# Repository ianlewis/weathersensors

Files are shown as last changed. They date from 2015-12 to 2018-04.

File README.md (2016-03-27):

# Home Sensors Project

This is my home sensors project.

## Architecture

The system will contain:

1. 2 temperature/humidity sensor modules for inside. One for upstairs and one for downstairs.
1. 1 temperature/humidity/barameter sensor module for outside (maybe also wind & rainfall).

Software will need to be written for each of the types of modules. Each of the
sensor modules will contain a web server which will return the current data
when queried. The aggregator module will polls data for each of the sensors and
streams that data to BigQuery.

Architecture

## Design

### Indoor sensor modules

The [indoor module](indoor_mod/) will read indoor temperature and humidity.

### Outdoor sensor modules

The [outdoor module](outdoor_mod/) will read outdoor temperature, humidity, atmospheric pressure, wind strength, wind direction, and rainfall.

### Aggregation App

The [aggregation server](aggre_mod/) will aggregate data and store it in BigQuery.

# Notes

## Local Development

Flashing devices locally requires the
[particle-cli](https://github.com/spark/particle-cli) and
[dfu-util](http://dfu-util.sourceforge.net/).

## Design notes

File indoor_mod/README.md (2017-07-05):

# Indoor sensor modules

The indoor sensor modules will be powered by the [Particle
Photon](https://particle.io/) module. Photons are USB powered and have an
integrated ARM microcontroller and wifi module. The device will use the
Particle Pub/Sub API to send new data to the aggregator module.

The indoor sensor modules will use the [AM2302 temperature & humidity
sensor](https://www.adafruit.com/products/393) and use a enclosure.

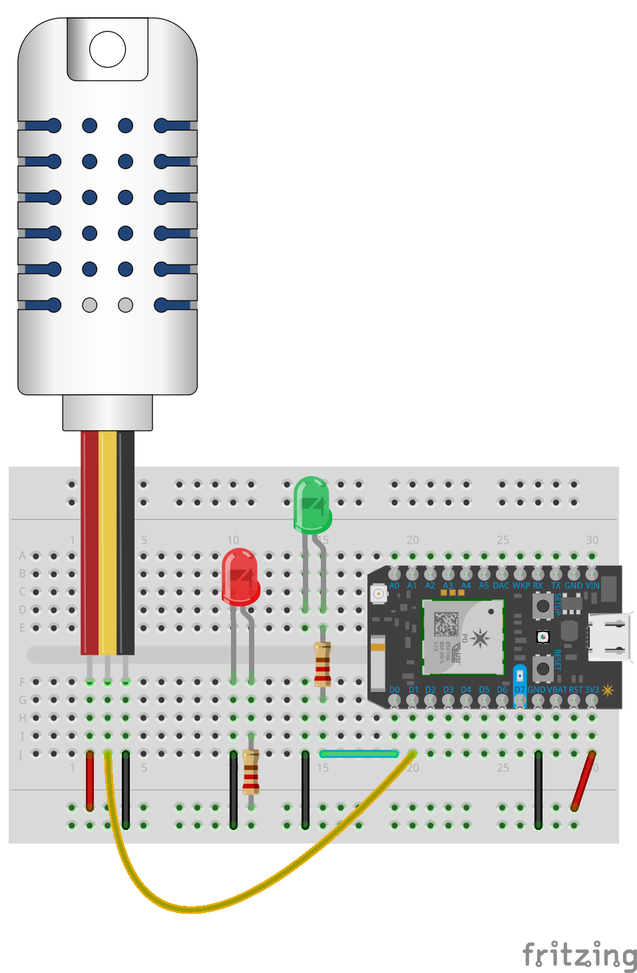
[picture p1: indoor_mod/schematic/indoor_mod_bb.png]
Schematic


## Build the Firmware

Building the firmware by running make in the firmware directory. You can learn more about building the photon firmware by reading the firmware [Getting Started](https://github.com/spark/firmware/blob/develop/docs/gettingstarted.md) page.

```
$ cd firmware
$ make
```

If you run into errors building the firmware sometimes they will resolve themselves by building from a clean version.

```
$ make clean firmware
```

## Flash the Firmware Locally

Flashing requires the `dfu-util` tool.

```
$ make program-dfu
```

## Flash the Firmware Remotely

Flashing the firmware remotely requires the [particle-cli](https://docs.particle.io/guide/tools-and-features/cli/photon/) tool.

TODO: Add instructions.

## Datasheets

Find info about the components used in the [datasheets](datasheets/) directory.

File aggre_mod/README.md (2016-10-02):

# Aggregator Module

This module is a data aggregator. It receives data published from devices and
forwards it on to Fluentd/BigQuery.

# Architecture

Architecture

# Setup

aggre\_mod is deployed to [Google Container
Engine](https://cloud.google.com/container-engine/) where it runs in a
[pod](http://kubernetes.io/v1.0/docs/user-guide/pods.html) with Fluentd.

The app is deployed via the following steps. You will need to have
make, Docker, and the Google Cloud SDK installed:

1. Create a BigQuery dataset.

        bq mk --description "Sensors Dataset" weathersensors

1. Create a BigQuery table.

        bq mk --description "Sensor data" weathersensors.sensordata schema.json

1. Create and push the container images (make sure you have the Google Cloud SDK installed and configured for your project):

        make clean image push

1. [Create a service account](https://cloud.google.com/iam/docs/creating-managing-service-accounts) and get the JSON key. Save it to the file 'service-account.json'.
1. Create the configmap:

        kubectl create configmap aggremod-conf \
            --from-literal=project-id=$(gcloud config list project | awk 'FNR==2 { print $3 }') \
            --from-literal=bigquery-dataset=weathersensors \
            --from-literal=bigquery-table=sensordata

1. Create the secret:

        kubectl create secret generic aggremod-secret \
            --from-literal=token=[particle.io token] \
            --from-file=service-account.json

1. Create the aggre\_mod Deployment:

        kubectl create -f deploy.yaml

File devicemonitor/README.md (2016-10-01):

# Device Monitor

This directory contains a device monitor that monitors [Particle](https://particle.io/) devices and creates error reports in [Stackdriver Error Reporting](https://cloud.google.com/error-reporting/) if they are offline for too long. The device monitor monitors the online status of each device or a subset of devices by polling the [Particle Devices API](https://docs.particle.io/reference/api/#devices).

## Usage

### Command line arguments

```shell
$ ./devicemonitor -help
Usage of ./devicemonitor:
  -access-token string
    	The path to a file containing the Particle API access token.
  -device-list string
    	The path to a text file of device IDs (one per line) to monitor. If not specified, all devices are monitored.
  -device-timeout int
    	The time that a device can be offline before an error is produced. (default 300)
  -host string
    	The web server address for health checks. (default ":8080")
  -poll-interval int
    	API polling interval in seconds. (default 30)
  -project string
    	The Google Cloud Platform project ID for the Error Reporting API.
  -version
    	Print the version and exit.
```

### Environment Variables

Some environment variables can be set to configure the monitor.

- **ADDRESS**: The address of the health check web server to bind to. This is overridden by the `-host` command line argument.
- **DEVICE_LIST_PATH**: The path to a text file of device IDs (one per line) to monitor. If not specified, all devices are monitored. This is overridden by the `-device-list` command line argument.
- **DEVICE_TIMEOUT**: The time in seconds that a device can be offline before an error is produced. This is overridden by the `-device-timeout` command line argument.
- **ACCESS_TOKEN_PATH**: The path to a file containing the Particle API access token. This is overridden by the `-access-token` command line argument.
- **POLL_INTERVAL**: API polling interval in seconds. This is overridden by the `-poll-interval` command line argument.
- **GCP_PROJECT**: The Google Cloud Platform project ID for the Error Reporting API. This is overridden by the `-project` command line argument.
- **GOOGLE_APPLICATION_CREDENTIALS**: The path to the service account JSON file. **Required.**

## Setup

This section will take you through how to set up the required files for the device monitor.

### Create the Service Account

Make sure you have the [Google Cloud Platform SDK](https://cloud.google.com/sdk/) installed and authenticated.

[Create a service account](https://cloud.google.com/iam/docs/creating-managing-service-accounts) for the device monitor.

```shell
$ gcloud iam service-accounts create devicemonitor --display-name "devicemonitor"
```

Create a service account key. This will output a `service-account.json` file.

```shell
$ gcloud iam service-accounts keys create service-account.json --iam-account devicemonitor@my-project.iam.gserviceaccount.com
```

### Create the Token file

Copy your [Particle access token](https://docs.particle.io/reference/api/#authentication) to the `token` file.

```shell
$ echo 9876987698769876987698769876987698769876 > token
```

### Create a Device List (Optional)

Create a list of device you want to monitor. This is optional. If you don't add a device list then all devices returned by the API will be monitored. The path to this file can be passed to the `DEVICE_LIST_PATH` environment variable or to the `-device-list` command line argument.

```shell
$ echo 0123456789abc > devices
$ echo 53ff6f0650723 >> devices
$ echo 53ff291839887 >> devices
```

### Build and Run the App

Building the app will require a relatively recent Go toolchain.

```shell
$ go generate
$ go build .
```

Alternatively, you can use make.

```shell
$ make clean devicemonitor
```

You can run the app from anywhere given yout pass in the right command line arguments.

```shell
$ GOOGLE_APPLICATION_CREDENTIALS=service-account.json ./devicemonitor -project-id=my-project -access-token=token
```

## Deploy on Kubernetes

There are Kubernetes deployment files included in the repository.

### Create the Secrets

Create the necessary secret.

```shell
$ kubectl create secret generic devicemonitor-secret --from-file=service-account.json --from-file=token
secret "devicemonitor-secret" created
```

### Create the ConfigMap

Create the ConfigMap by giving it a path to the `devices` file and passing it your Google Cloud Platform project ID.

```shell
$ kubectl create configmap devicemonitor-conf --from-file=devices --from-literal=project-id=my-project
configmap "devicemonitor-conf" created
```

### Deploy the Device Monitor

Create the deployment in Kubernetes.

```shell
$ kubectl create -f deploy.yaml
deployment "devicemonitor" created.
```

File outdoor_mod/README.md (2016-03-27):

# Outdoor sensor modules

The indoor sensor modules will also be powered by the [Particle
Photon](https://store.particle.io/?product=particle-photon) module. Photons are
USB powered and have an integrated ARM microcontroller and wifi module. The
device will use the Particle Pub/Sub API to send new data to the aggregator
module.

The outdoor sensor modules will use the [AM2315 - Encased I2C
Temperature/Humidity Sensor](https://www.adafruit.com/products/1293). The
outdoor module will also contain the [BMP180 Barometric
Pressure/Temperature/Altitude Sensor](https://www.adafruit.com/products/1603)

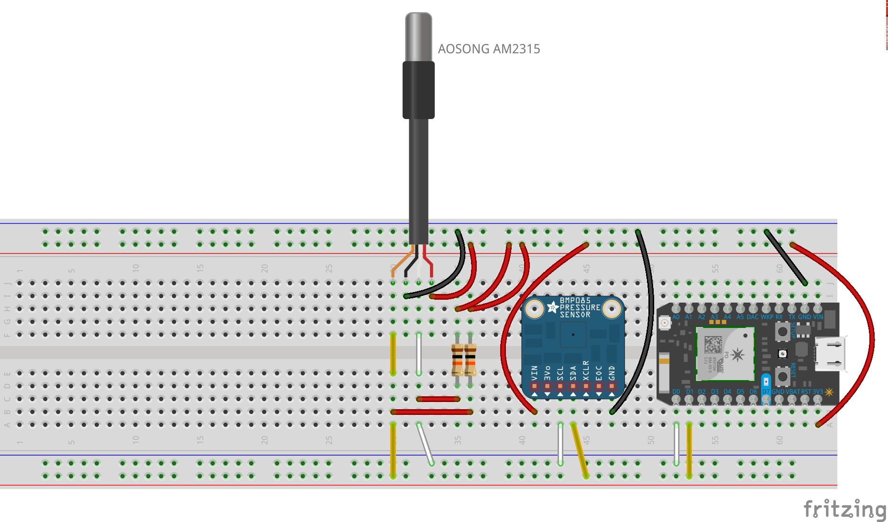
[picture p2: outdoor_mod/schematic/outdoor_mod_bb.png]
Schematic


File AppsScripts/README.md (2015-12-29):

This directory contains Google Apps Scripts widgets for displaying
temperature data in graph format.

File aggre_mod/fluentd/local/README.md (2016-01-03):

# Local Fluentd

This directory contains config for running a local fluentd that outputs to
stdout. It is inteded to be used for local debugging.

# Running Fluentd

It's easiest to run fluentd in a container. Run it in the current directory
with the following command using Docker.

    $ docker run -p 24224:24224 -v `pwd`:/fluentd/etc fluent/fluentd

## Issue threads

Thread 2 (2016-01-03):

Log when a device stops sending data.

IanLewis, 2016-01-03:

IanLewis, 2016-01-18:
This was fixed by 79abe1a6064c9d057f8d7480a1a83010c33fb82d

Closed 2016-01-18.

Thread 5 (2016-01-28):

AM2302 returns -4

IanLewis, 2016-01-28:
The AM2302 seems to have errors sometimes and returns a temperature of -4. This affects the data when doing averages.

Maybe have the devices query the AM2302 again when the returned value is -4?

Closed 2016-03-27.

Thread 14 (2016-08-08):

Update docs for indoor_mod

IanLewis, 2016-08-08:
Update the docs for indoor_mod

- Info on how to build the firmware
- Info on how to flash to the device
- Info on building/soldering the board

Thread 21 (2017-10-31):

device monitor log output shouldn't write to stderr

ianlewis, 2017-10-31:
Only errors should be written to stderr, not all logs

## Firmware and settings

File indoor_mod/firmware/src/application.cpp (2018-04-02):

/*
Firmware application for indoor_mod test sensor. The device includes
a DHT22 temperature/humidity sensor
*/

/* Includes ------------------------------------------------------------------*/  

#include "application.h"
#include "config.h"
#include "version.h"

// PietteTech DHT22 library.
// https://github.com/piettetech/PietteTech_DHT
#include "third_party/PietteTech_DHT/firmware/PietteTech_DHT.h"

// MQTT TLS library
// https://github.com/hirotakaster/MQTT-TLS
#include "third_party/MQTT-TLS/src/MQTT-TLS.h"

#define LETS_ENCRYPT_CA_PEM                                             \
"-----BEGIN CERTIFICATE----- \r\n"                                      \
"MIIFjTCCA3WgAwIBAgIRANOxciY0IzLc9AUoUSrsnGowDQYJKoZIhvcNAQELBQAw\r\n"  \
"TzELMAkGA1UEBhMCVVMxKTAnBgNVBAoTIEludGVybmV0IFNlY3VyaXR5IFJlc2Vh\r\n"  \
"cmNoIEdyb3VwMRUwEwYDVQQDEwxJU1JHIFJvb3QgWDEwHhcNMTYxMDA2MTU0MzU1\r\n"  \
"WhcNMjExMDA2MTU0MzU1WjBKMQswCQYDVQQGEwJVUzEWMBQGA1UEChMNTGV0J3Mg\r\n"  \
"RW5jcnlwdDEjMCEGA1UEAxMaTGV0J3MgRW5jcnlwdCBBdXRob3JpdHkgWDMwggEi\r\n"  \
"MA0GCSqGSIb3DQEBAQUAA4IBDwAwggEKAoIBAQCc0wzwWuUuR7dyXTeDs2hjMOrX\r\n"  \
"NSYZJeG9vjXxcJIvt7hLQQWrqZ41CFjssSrEaIcLo+N15Obzp2JxunmBYB/XkZqf\r\n"  \
"89B4Z3HIaQ6Vkc/+5pnpYDxIzH7KTXcSJJ1HG1rrueweNwAcnKx7pwXqzkrrvUHl\r\n"  \
"Npi5y/1tPJZo3yMqQpAMhnRnyH+lmrhSYRQTP2XpgofL2/oOVvaGifOFP5eGr7Dc\r\n"  \
"Gu9rDZUWfcQroGWymQQ2dYBrrErzG5BJeC+ilk8qICUpBMZ0wNAxzY8xOJUWuqgz\r\n"  \
"uEPxsR/DMH+ieTETPS02+OP88jNquTkxxa/EjQ0dZBYzqvqEKbbUC8DYfcOTAgMB\r\n"  \
"AAGjggFnMIIBYzAOBgNVHQ8BAf8EBAMCAYYwEgYDVR0TAQH/BAgwBgEB/wIBADBU\r\n"  \
"BgNVHSAETTBLMAgGBmeBDAECATA/BgsrBgEEAYLfEwEBATAwMC4GCCsGAQUFBwIB\r\n"  \
"FiJodHRwOi8vY3BzLnJvb3QteDEubGV0c2VuY3J5cHQub3JnMB0GA1UdDgQWBBSo\r\n"  \
"SmpjBH3duubRObemRWXv86jsoTAzBgNVHR8ELDAqMCigJqAkhiJodHRwOi8vY3Js\r\n"  \
"LnJvb3QteDEubGV0c2VuY3J5cHQub3JnMHIGCCsGAQUFBwEBBGYwZDAwBggrBgEF\r\n"  \
"BQcwAYYkaHR0cDovL29jc3Aucm9vdC14MS5sZXRzZW5jcnlwdC5vcmcvMDAGCCsG\r\n"  \
"AQUFBzAChiRodHRwOi8vY2VydC5yb290LXgxLmxldHNlbmNyeXB0Lm9yZy8wHwYD\r\n"  \
"VR0jBBgwFoAUebRZ5nu25eQBc4AIiMgaWPbpm24wDQYJKoZIhvcNAQELBQADggIB\r\n"  \
"ABnPdSA0LTqmRf/Q1eaM2jLonG4bQdEnqOJQ8nCqxOeTRrToEKtwT++36gTSlBGx\r\n"  \
"A/5dut82jJQ2jxN8RI8L9QFXrWi4xXnA2EqA10yjHiR6H9cj6MFiOnb5In1eWsRM\r\n"  \
"UM2v3e9tNsCAgBukPHAg1lQh07rvFKm/Bz9BCjaxorALINUfZ9DD64j2igLIxle2\r\n"  \
"DPxW8dI/F2loHMjXZjqG8RkqZUdoxtID5+90FgsGIfkMpqgRS05f4zPbCEHqCXl1\r\n"  \
"eO5HyELTgcVlLXXQDgAWnRzut1hFJeczY1tjQQno6f6s+nMydLN26WuU4s3UYvOu\r\n"  \
"OsUxRlJu7TSRHqDC3lSE5XggVkzdaPkuKGQbGpny+01/47hfXXNB7HntWNZ6N2Vw\r\n"  \
"p7G6OfY+YQrZwIaQmhrIqJZuigsrbe3W+gdn5ykE9+Ky0VgVUsfxo52mwFYs1JKY\r\n"  \
"2PGDuWx8M6DlS6qQkvHaRUo0FMd8TsSlbF0/v965qGFKhSDeQoMpYnwcmQilRh/0\r\n"  \
"ayLThlHLN81gSkJjVrPI0Y8xCVPB4twb1PFUd2fPM3sA1tJ83sZ5v8vgFv2yofKR\r\n"  \
"PB0t6JzUA81mSqM3kxl5e+IZwhYAyO0OTg3/fs8HqGTNKd9BqoUwSRBzp06JMg5b\r\n"  \
"rUCGwbCUDI0mxadJ3Bz4WxR6fyNpBK2yAinWEsikxqEt\r\n"  \
"-----END CERTIFICATE----- "
const char letsencryptCaPem[] = LETS_ENCRYPT_CA_PEM;

const int LOOP_INTERVAL_SEC = 60;
const int READ_LED = D0;
const int DHTPIN = D1;

void dht_wrapper(); // must be declared before the lib initialization

// Initialize the DHT22 sensor.
PietteTech_DHT dht(DHTPIN, DHT22, dht_wrapper);

// This wrapper is in charge of calling
// must be defined like this for the lib work
void dht_wrapper() {
    dht.isrCallback();
}

#define ONE_DAY_MILLIS (24 * 60 * 60 * 1000)
unsigned long lastSync = millis();

double humidity = 0;
double temp = 0;
String deviceName = String("");
String location = String(CONFIG_LOCATION);
String localIP;
String deviceType = String("indoor_mod");
String version = String(gitversion);

struct State {
    bool wifiReady;
    bool particleConnected;
    bool mqttConnected;
    State() : wifiReady(false), particleConnected(false), mqttConnected(false) {}
    bool ready() {
        return wifiReady && particleConnected && mqttConnected; 
    }
};

State prevState, currentState;

// Initialized the client and set keepalive to 2 * loop interval
MQTT client(CONFIG_MQTT_HOST, CONFIG_MQTT_PORT, LOOP_INTERVAL_SEC*2, NULL);

/*
 * Sync the device time with the spark server.
 */
void syncTime() {
    if (millis() - lastSync > ONE_DAY_MILLIS) {
        // Request time synchronization from the Particle Cloud
        Particle.syncTime();
        lastSync = millis();
    }
}

void log(String msg) {
    if (Serial.isConnected()) {
        Serial.println(String("[") + String(Time.now()) + String("] ") + msg);
    }
}

void deviceNameHandler(const char *topic, const char *data) {
    deviceName = String(data);
    log("Got device name: "+deviceName);
}

void setup() {
    // start listening for clients
    Serial.begin(115200);

    pinMode(READ_LED, OUTPUT);

    Particle.variable("deviceType", deviceType);
    Particle.variable("humidity", humidity);
    Particle.variable("location", location);
    Particle.variable("temperature", temp);
    Particle.variable("localIP", localIP);
    Particle.variable("version", version);

    // Get the device name
    Particle.subscribe("particle/device/name", deviceNameHandler);
    Particle.publish("particle/device/name");

    // Enable tls. set Root CA pem file.
    client.enableTls(letsencryptCaPem, sizeof(letsencryptCaPem));

    // Delay 10 seconds so we can connect for debugging
    waitFor(Serial.isConnected, 10000);

    log("setup finished");
}

// The main loop that gets run forever.
void loop() {
    int extra = 0;

    // Sync with the Spark server if necessary.
    syncTime();

    // Wait for the deviceName before looping
    if (deviceName == "") {
        log("Waiting for device name...");
        delay(100);
        return;
    }

    // Run the mqtt client loop
    client.loop();

    currentState = State();
    currentState.wifiReady = WiFi.ready();
    currentState.particleConnected = Particle.connected();
    currentState.mqttConnected = client.isConnected();

    if (!currentState.mqttConnected) {
        // Attempt to re-connect to the MQTT server
        log("Connecting to mqtt server");
        if (client.connect(deviceName, CONFIG_MQTT_USERNAME, CONFIG_MQTT_PASSWORD)) {
            log("Connected to mqtt server");
        } else {
            log("Failed to connect to mqtt server");
        }
        currentState.mqttConnected = client.isConnected();
    }

    // Log changes
    if (!prevState.wifiReady && currentState.wifiReady) {
        log("Connected to WiFi");
    }
    if (!prevState.particleConnected && currentState.particleConnected) {
        log("Connected to Particle");
    }
    prevState = currentState;

    // If not ready then blink
    if (!currentState.ready()) {
        digitalWrite(READ_LED, HIGH);
        delay(1000);
        digitalWrite(READ_LED, LOW);
        delay(1000);
        return;
    }

    localIP = String(WiFi.localIP());

    // Turn on the READ LED.
    digitalWrite(READ_LED, HIGH);

    float fHumidity = dht.readHumidity();
    float fTemp = dht.readTemperature();

    // Sometimes the DHT sensor returns -4 for some reason.
    // Retry up to 3 times.
    int retries = 0;
    while ((fTemp == -4 || fHumidity == -4) && retries < 3) {
        // The DHT library only reads the sensor every 2 seconds.
        // Wait over 2 seconds before attempting another read.
        delay(2001);
        extra += 2001;

        fHumidity = dht.readHumidity();
        fTemp = dht.readTemperature();

        retries += 1;
    }

    // Ignore values that are exactly -4.
    if (fTemp != -4 && fHumidity != -4) {
        temp = fTemp;
        humidity = fHumidity;

        String data = String("{\"location\":\""+location+"\",\"timestamp\":" + String(Time.now()) + ",\"temperature\":" + String(temp) +",\"humidity\":" + String(humidity) + "}");
        client.publish("home/" + location + "/climate", data);

        log(data);
    }

    // Delay so that the READ LED stays on
    // for a little longer.
    delay(100);
    extra += 100;
    digitalWrite(READ_LED, LOW);

    // Send data every interval
    delay(1000 * LOOP_INTERVAL_SEC - extra);
}

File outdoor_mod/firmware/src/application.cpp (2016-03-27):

/*
Firmware application for outdoor_mod weather station.

The device includes a AM2315 temperature/humidity sensor which communicates
using i2c. i2c is implemented as a firmware library in Wire.h
*/

// AM2315 doesn't seem to be working. Disable for now.
#define ENABLE_AM2315 true
#define ENABLE_BMP180 true

/* Includes ------------------------------------------------------------------*/  

#include "application.h"

#if ENABLE_AM2315
// https://github.com/adafruit/Adafruit_AM2315
#include "Adafruit_AM2315.h"
#endif

#if ENABLE_BMP180
#include "Adafruit_BMP085_U.h"
#endif

#if ENABLE_AM2315
// Initialize the AM2315
Adafruit_AM2315 am2315;
#endif

#if ENABLE_BMP180
// Initialize the BMP180
Adafruit_BMP085_Unified bmp = Adafruit_BMP085_Unified(10085);
#endif

const int READ_LED = D2;

#define ONE_DAY_MILLIS (24 * 60 * 60 * 1000)
unsigned long lastSync = millis();

void log(String msg) {
    if (Serial.available()) {
        Serial.println(String("[") + String(Time.now()) + String("] ") + msg);
    }
}

/*
 * Sync the device time with the spark server.
 */
void syncTime() {
    if (millis() - lastSync > ONE_DAY_MILLIS) {
        log("Syncing time with cloud...");
        // Request time synchronization from the Particle Cloud
        Particle.syncTime();
        lastSync = millis();
        log("Syncing time with cloud...");
    }
}

double temp = 0;
double humidity = 0;
double pressure = 0;
String localIP;
String deviceType = String("outdoor_mod");

void setup() {
    Serial.begin(115200);

    pinMode(READ_LED, OUTPUT);

    Particle.variable("deviceType", deviceType);
    Particle.variable("humidity", humidity);
    Particle.variable("temperature", temp);
    Particle.variable("pressure", pressure);
    Particle.variable("localIP", localIP);

    // Delay 15 seconds so we can connect for debugging
    delay(15000);

#if ENABLE_AM2315
    log("Detecting AM2315...");
    if (!am2315.begin()) {
        log("Sensor not found, check wiring & pullups!");
        while(1);
    }
    log("AM2315 Detected.");
#endif

#if ENABLE_BMP180
    log("Detecting BMP180...");
    if (!bmp.begin()) {
        /* There was a problem detecting the BMP085 ... check your connections */
        Serial.print("Ooops, no BMP085 detected ... Check your wiring or I2C ADDR!");
        while(1);
    }
    log("BMP180 Detected.");
#endif
}

void loop() {
    // Sync with the Spark server if necessary.
    syncTime();

    String data = String("timestamp:") + String(Time.now());

    // Turn on the READ LED.
    digitalWrite(READ_LED, HIGH);

    float fTemp, fHumidity;

#if ENABLE_AM2315
    am2315.readTemperatureAndHumidity(fTemp, fHumidity);
    temp = fTemp;
    humidity = fHumidity;

    data += String("\ttemp:") + String(temp) + String("\thumidity:") + String(humidity);
#endif

#if ENABLE_BMP180
    /* Get a new sensor event */ 
    sensors_event_t event;
    bmp.getEvent(&event);
 
    /* Barometric pressure is measure in hPa */
    if (event.pressure) {
        data += String("\tpressure:") + String(event.pressure);
        pressure = event.pressure;
    }
#endif

    localIP = String(WiFi.localIP());

    Particle.publish("weatherdata", data);
    log(data);

    // Delay so that the READ LED stays on
    // for a little longer.
    delay(100);
    digitalWrite(READ_LED, LOW);

    delay(1000 * 60 - 100);
}

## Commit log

2015-07-20 Added Fritzing sketches
    [indoor_mod.fzz, outdoor_mod.fzz]
2015-07-20 Updated indoor_mod sketch
    [indoor_mod.fzz]
2015-09-12 Updated aggre_mod to support device discovery
2015-09-12 Updated the device firmware to support discovery
2015-10-04 Updated to use device registration again
2015-10-21 Use Particle cloud API
    Updated to use the particle.io Cloud API. Temperature data is sent via
    the Particle.publish() function. The aggre_mod app runs on GKE and
    subscribes to the data.
2015-10-21 Updated indoor_mod schematic
    [indoor_mod.fzz]
2015-11-07 Added support for device state
2015-12-30 Added the current temp & humidity to widget
2016-01-03 Added device update and logging.
2016-01-10 Added the Adafruit unified sensor lib
2016-01-10 Added indoor_mod_bb schematic diag image
2016-01-10 Added partly finished outdoor_mod schematic
    [outdoor_mod.fzz]
2016-03-27 Retry if temp or humidity is -4. fixes #5
    [application.cpp]
2016-03-27 Use host mounted ca-certs. fixes #7
2016-10-01 Added a device monitor.
2016-10-01 Updated devicemonitor deployment
    - Changed polling interval to 60s since I don't need low latency.
    - Increased memory limits since the app was getting OOMKilled
2016-10-02 Added .gitignore to devicemonitor
2016-10-02 Updated aggre_mod fluentd
    - Updated fluentd to 0.12.29
    - Added a Makefile to build the fluentd image.
    - Pinned fluentd version and stop using latest.
    - Pinned version of fluent-plugin-bigquery
    - Switched to using a JSON service account key
    - Had to remove the certs host mount on fluentd because newer fluentd images use Alpine linux and the GCI host /etc/ssl/certs directory seems incompatible with Alpine.
    - Increased resource limits on fluentd pod so that it runs reasonably on machines that enforce CPU limits.
2016-10-29 Updated limits for the devicemonitor
2017-07-05 Added a status indicator mode
    When the Wifi or Particle API is not connected, just blink on the read
    LED.
